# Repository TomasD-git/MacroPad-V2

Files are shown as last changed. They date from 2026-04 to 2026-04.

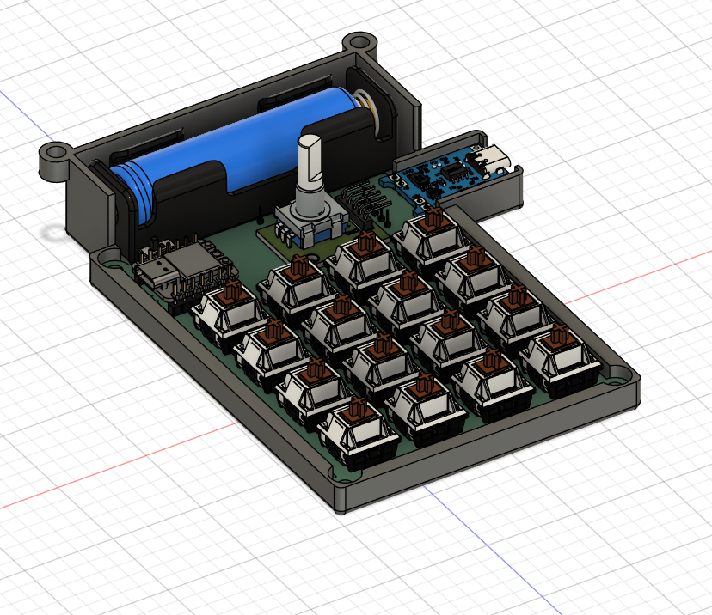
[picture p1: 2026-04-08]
Pictures/Screenshot 2026-04-08 103458.png

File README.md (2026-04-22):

# MacroPad-V2

A compact 16-key macro pad with rotary encoder and built-in battery — powered by ESP32, fully wireless.  



## Features

- 16 Programmable Keys  
- Rotary Encoder  
- Battery Powered  
- ESP32 with bluetooth  

## How It Works

The MacroPad-V2 uses a seeed xiao ESP32 S3 to manage key matrix and rotary encoder.  

Power is managed by a charging module.  

Firmware handles Bluetooth. The case is 3D printed, with space for the PCB, battery, keys and encoder.  

<details>
  <summary>Pictures</summary>
  







</details>

<details>
<summary>BOM</summary>

| Name | Purpose | Quantity | Total Cost (USD) | Link | Distributor |
|---|---|---|---|---|---|
| PCB | How would i even make it without PCB | 1 | 11.34 | https://jlcpcb.com | jlcpcb |
| Pin header 2.54mm | soldered onto the pcb then on top of that is the esp32(so it can be visible), the rotary encoder needs this as well | 1 | 3.08 | https://www.aliexpress.com/item/4000873858801.html | Aliepress |
| 1N4148W T4 SOD-123(Diode) | needed in switch matrix(prevents ghosting) | 1 | 2.16 | https://www.aliexpress.com/item/1005010653199938.html | Aliexpress |
| Seeed xiao ESP32 S3 | brain of everything, needed to power use and control all switches and rotary encoder | 1 | 9.06 | https://www.aliexpress.com/item/1005007341749305.html | Aliepress |
| M4 screws 20pcs, 8mm | screwed into heatset inserts to hold case and pcb together | 1 | 2.16 | https://www.aliexpress.com/item/32810872544.html | Aliexpress |
| Heatset inserts, M4 (OD5mm) 30pcs, Length 3mm | Will be melted into the 3D printed case and screws will be inserted into it to hold the case together | 1 | 2.43 | https://www.aliexpress.com/item/1005008666672949.html | Aliexpress |
| Battery holder | Holds battery in place | 1 | 1.84 | https://www.aliexpress.com/item/1005006783038553.html | Aliexpress |
| Battery | to store electricity and later power the esp32 | 1 | 8.85 | https://www.aliexpress.com/item/32810182330.html | Aliexpress |
| Slide switch | shut power to esp32 so it wont consume electricity when not used | 1 | 1.8 | https://www.aliexpress.com/item/1005005633418066.html | Aliexpress |
| Charging module | safely power esp32 and charge battery | 1 | 2.0 | https://www.aliexpress.com/item/1005007176376691.html | Aliexpress |
| Key switches | To use the macropad, (Self sourced) | 1 | 0.0 | https://www.aliexpress.com/item/1005007666734237.html | Aliexpress |
| Rotary encoder | is a part on the pcb | 1 | 1.47 | https://www.aliexpress.com/item/1005009040530746.html | Aliexpress |

</details>

<details>
  <summary>License</summary>

### MIT License

**Copyright (c) [2026] [TomasD-git]**

Permission is hereby granted, free of charge, to any person obtaining a copy
of this software and associated documentation files (the "Software"), to deal
in the Software without restriction, including without limitation the rights
to use, copy, modify, merge, publish, distribute, sublicense, and/or sell
copies of the Software, and to permit persons to whom the Software is
furnished to do so, subject to the following conditions:

The above copyright notice and this permission notice shall be included in all
copies or substantial portions of the Software.

THE SOFTWARE IS PROVIDED "AS IS", WITHOUT WARRANTY OF ANY KIND, EXPRESS OR
IMPLIED, INCLUDING BUT NOT LIMITED TO THE WARRANTIES OF MERCHANTABILITY,
FITNESS FOR A PARTICULAR PURPOSE AND NONINFRINGEMENT. IN NO EVENT SHALL THE
AUTHORS OR COPYRIGHT HOLDERS BE LIABLE FOR ANY CLAIM, DAMAGES OR OTHER
LIABILITY, WHETHER IN AN ACTION OF CONTRACT, TORT OR OTHERWISE, ARISING FROM,
OUT OF OR IN CONNECTION WITH THE SOFTWARE OR THE USE OR OTHER DEALINGS IN THE
SOFTWARE.

</details>

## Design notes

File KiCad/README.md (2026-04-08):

# Here you can find all KiCad related files

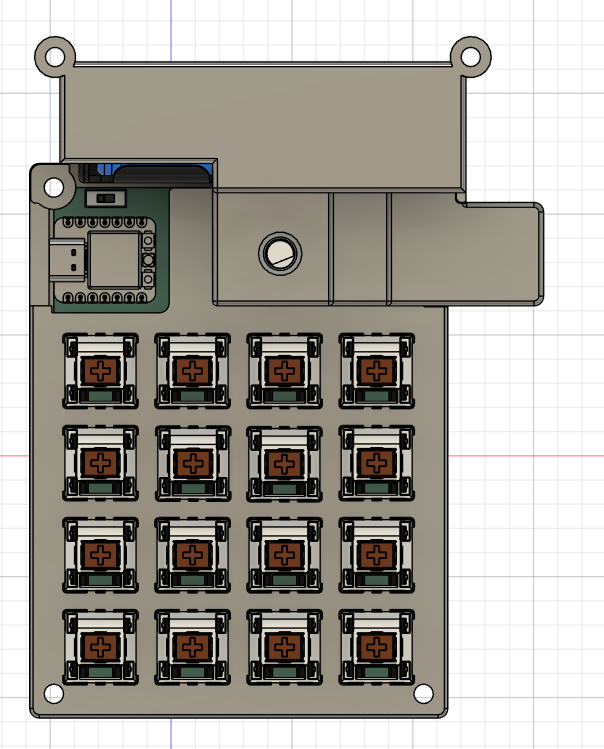
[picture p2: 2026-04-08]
Pictures/Screenshot 2026-04-08 103435.png

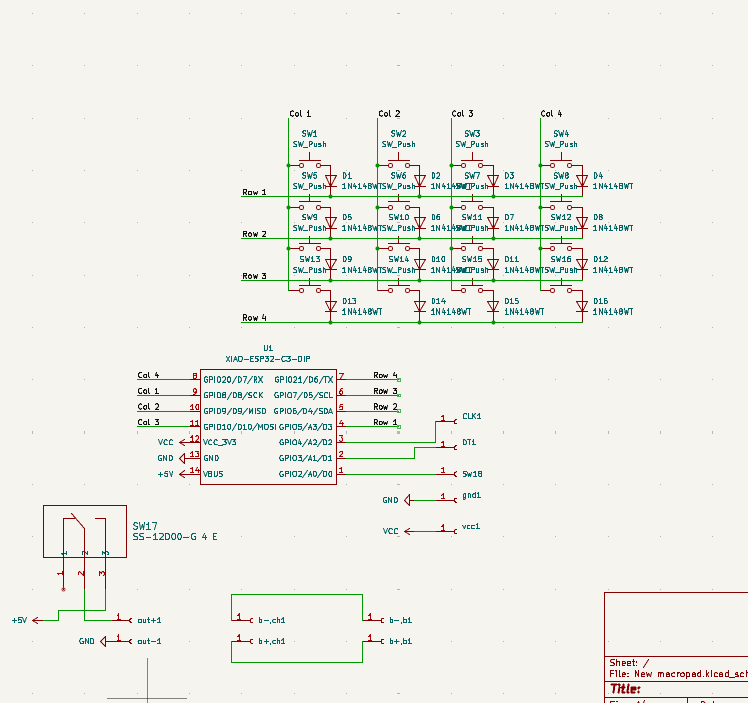
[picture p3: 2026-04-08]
Pictures/Screenshot 2026-04-08 092705.png

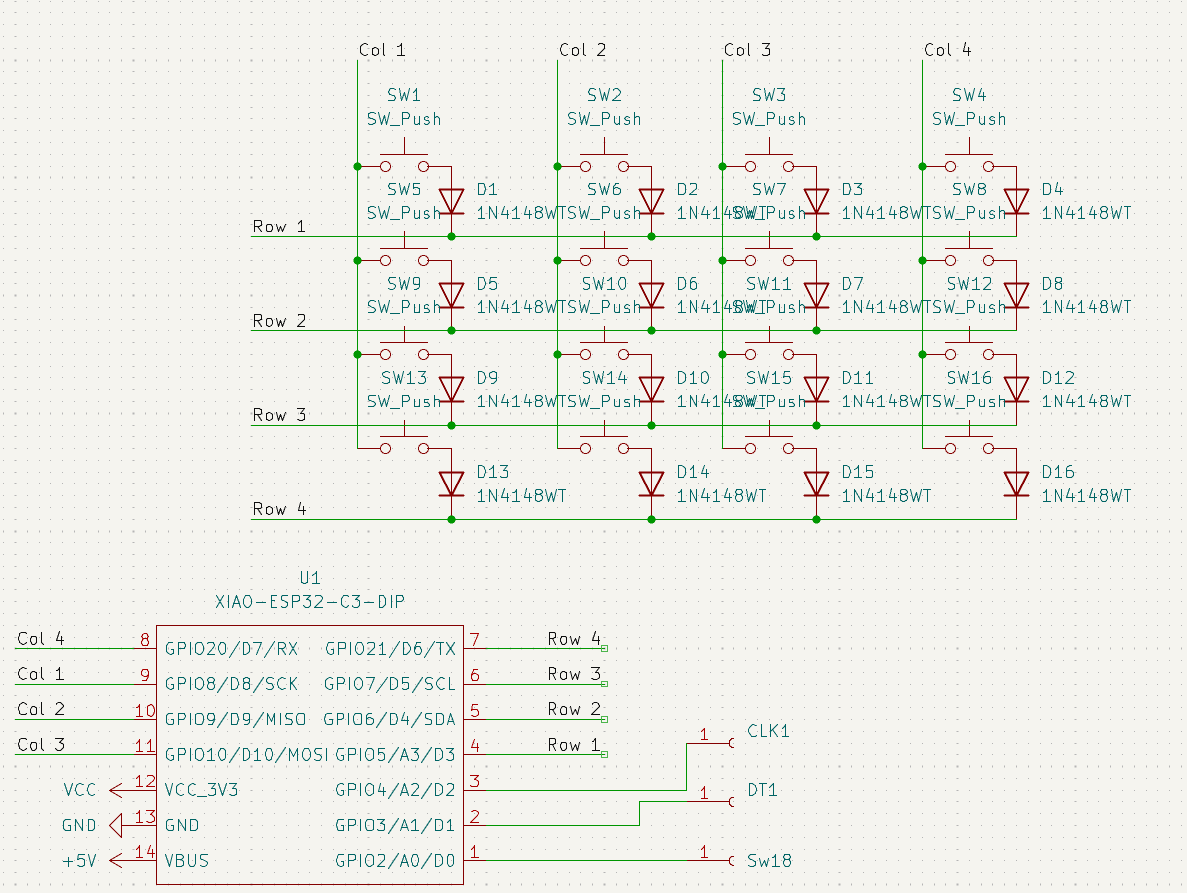
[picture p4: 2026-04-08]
Pictures/Screenshot 2026-04-08 092722.png

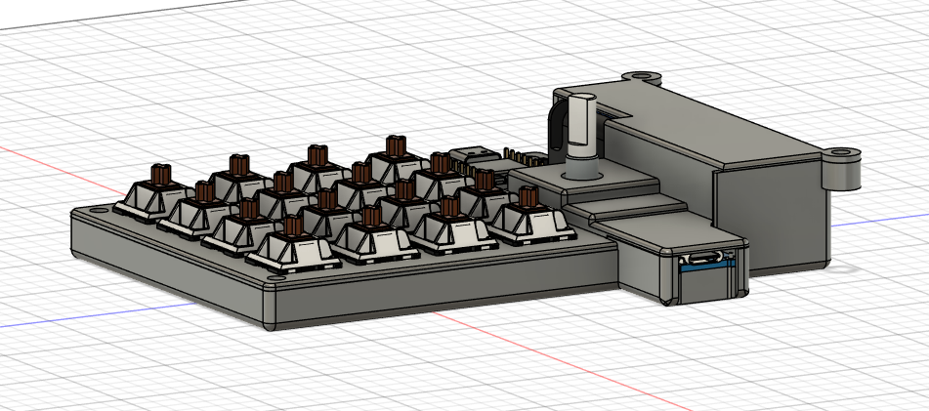
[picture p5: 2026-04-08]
Pictures/Screenshot 2026-04-08 103441.png

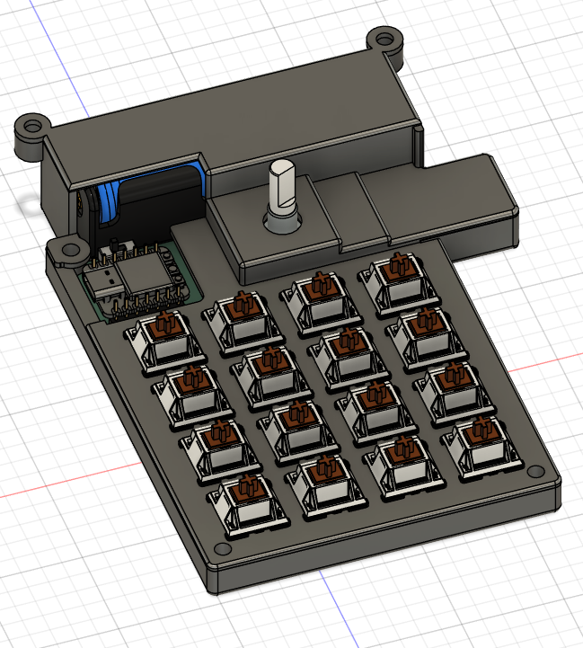
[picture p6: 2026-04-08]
Pictures/Screenshot 2026-04-08 103423.png

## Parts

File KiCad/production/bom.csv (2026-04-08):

Designator | Footprint | Quantity | Value | LCSC Part #
B+,B, B+,CH, B-,B, B-,CH, CLK, DT, GND, OUT+, OUT-, SW, VCC | PinHeader_1x01_P1.00mm_Vertical | 11 | Conn_01x01_Socket
D1, D10, D11, D12, D13, D14, D15, D16, D2, D3, D4, D5, D6, D7, D8, D9 | D_SOD-123 | 16 | 1N4148WT
SW1, SW10, SW11, SW12, SW13, SW14, SW15, SW16, SW2, SW3, SW4, SW5, SW6, SW7, SW8, SW9 | SW_Cherry_MX_PCB_1.00u | 16 | SW_Push
SW17 | 1P2T_SS-12D00_CNK | 1 | SS-12D00-G 4 E
U1 | Xiao_rp2040_AH_Pogo | 1 | XIAO-ESP32-C3-DIP

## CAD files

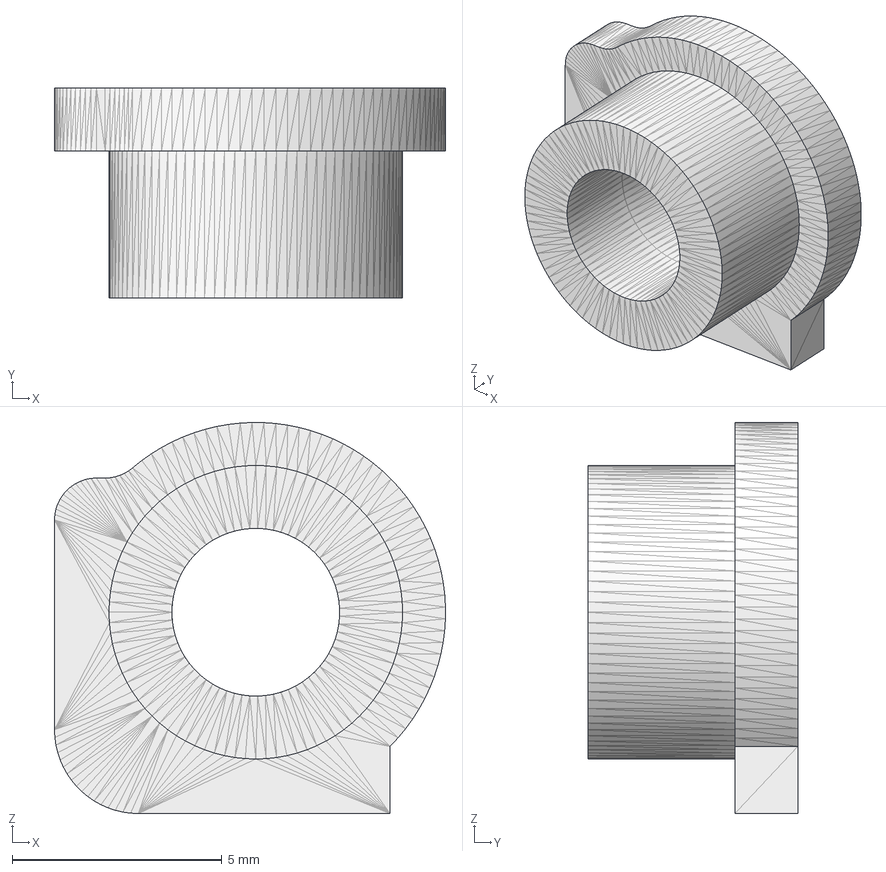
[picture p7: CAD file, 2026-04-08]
CAD/Top2.step
9.32 x 5.00 x 9.32 mm

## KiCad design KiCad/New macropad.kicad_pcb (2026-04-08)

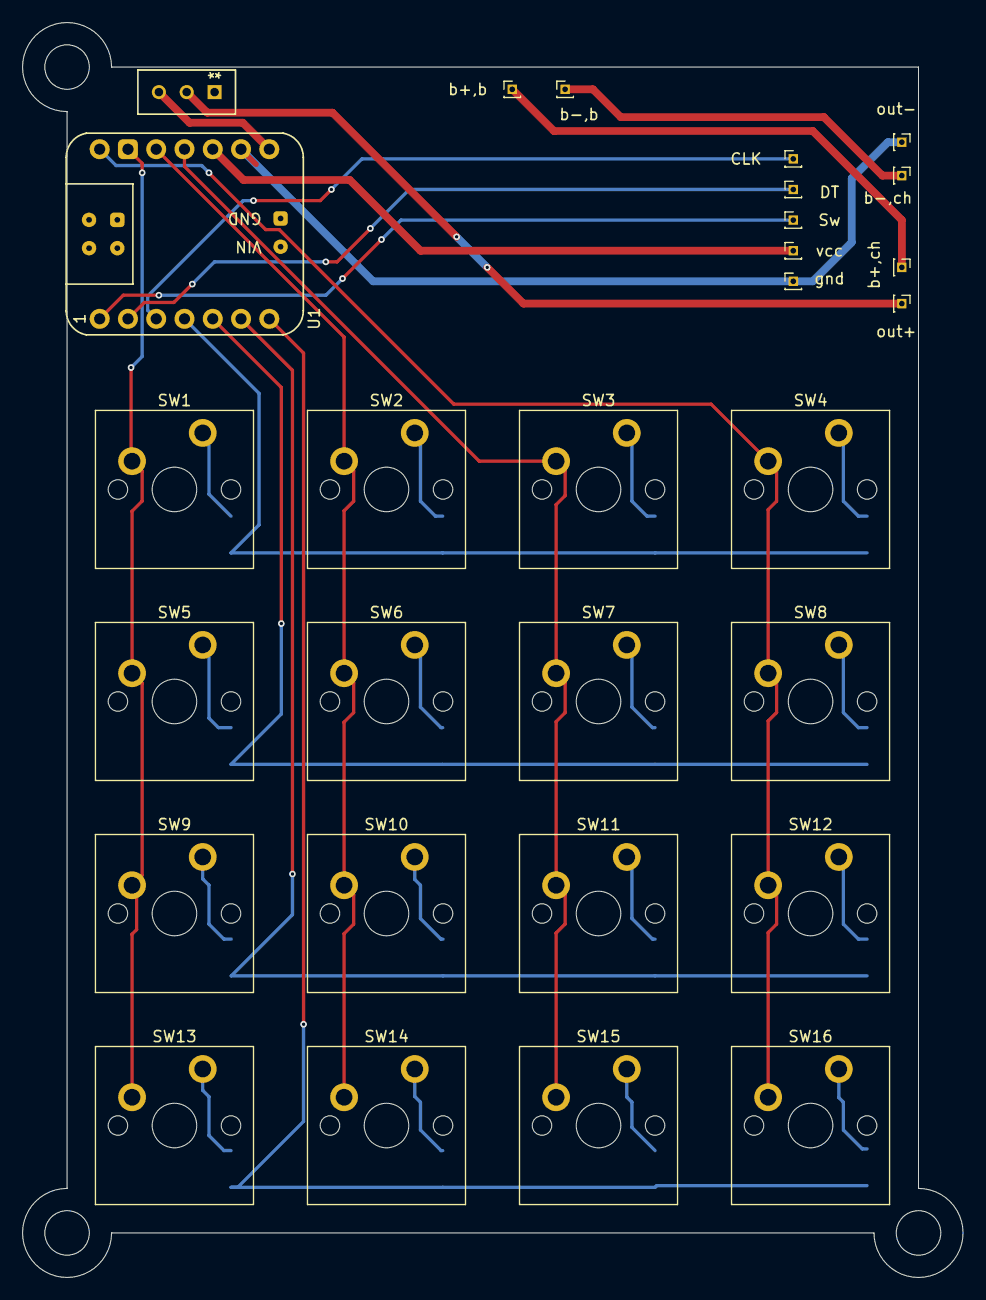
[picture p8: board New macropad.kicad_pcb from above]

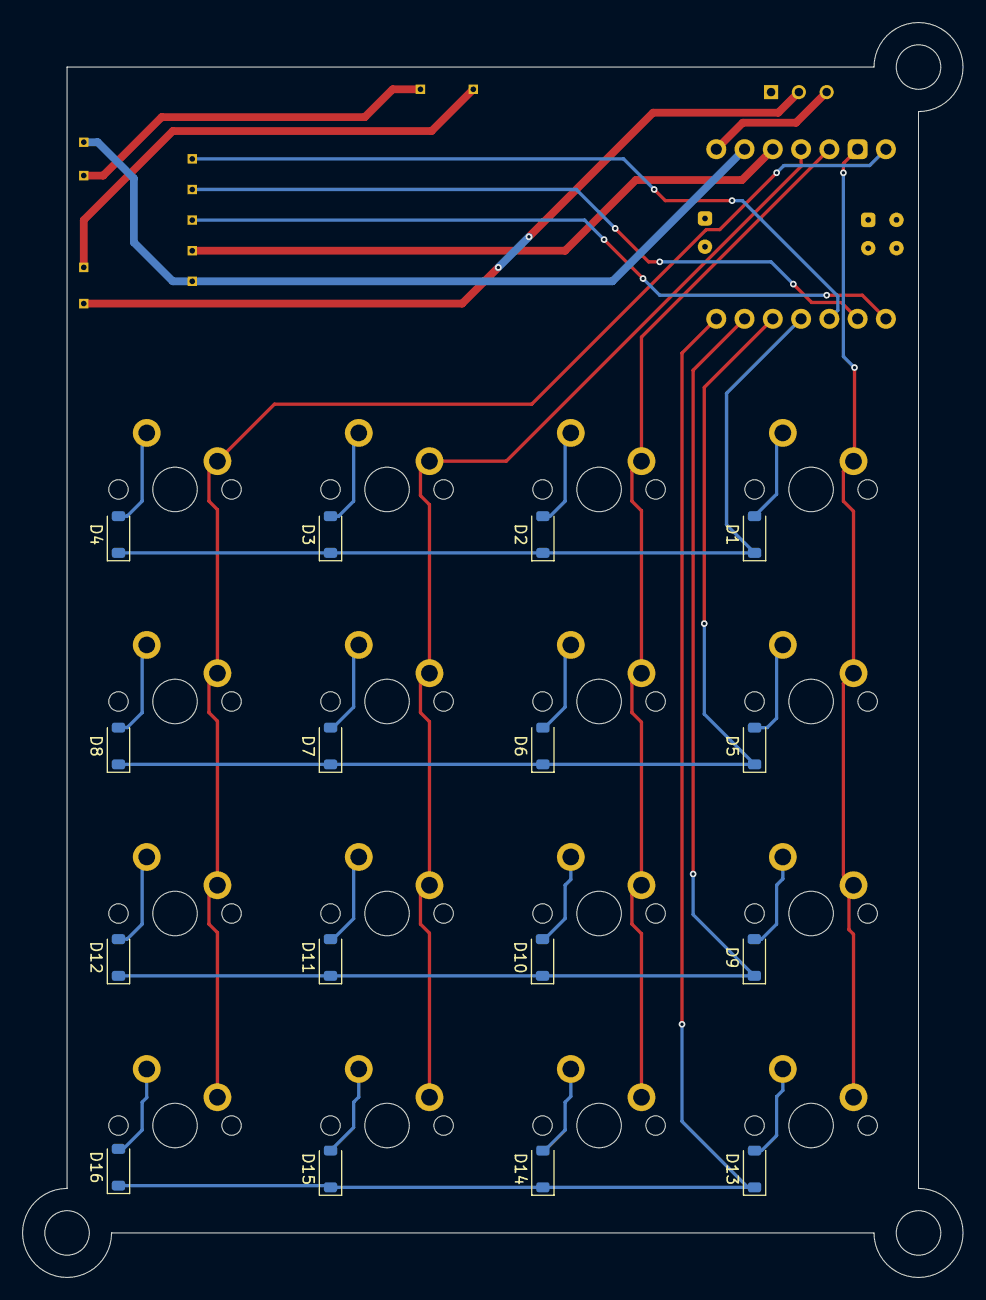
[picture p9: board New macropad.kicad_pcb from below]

Board: 2 copper layers, 84.5 x 112.7 mm, 45 parts (16 on the bottom side), 33 nets.

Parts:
CLK: Conn_01x01_Socket; PinHeader_1x01_P1.00mm_Vertical
D1, D2, D3, D4, D5, D6, D7, D8, D9, D10, D11, D12, D13, D14, D15, D16: 1N4148WT; D_SOD-123
DT: Conn_01x01_Socket; PinHeader_1x01_P1.00mm_Vertical
SW1, SW2, SW3, SW4, SW5, SW6, SW7, SW8, SW9, SW10, SW11, SW12, SW13, SW14, SW15, SW16: SW_Push; SW_Cherry_MX_PCB_1.00u
SW17: SS-12D00-G 4 E; 1P2T_SS-12D00_CNK
Sw: Conn_01x01_Socket; PinHeader_1x01_P1.00mm_Vertical
U1: XIAO-ESP32-C3-DIP; Xiao_rp2040_AH_Pogo
b+,b: Conn_01x01_Socket; PinHeader_1x01_P1.00mm_Vertical
b+,ch: Conn_01x01_Socket; PinHeader_1x01_P1.00mm_Vertical
b-,b: Conn_01x01_Socket; PinHeader_1x01_P1.00mm_Vertical
b-,ch: Conn_01x01_Socket; PinHeader_1x01_P1.00mm_Vertical
gnd: Conn_01x01_Socket; PinHeader_1x01_P1.00mm_Vertical
out+: Conn_01x01_Socket; PinHeader_1x01_P1.00mm_Vertical
out-: Conn_01x01_Socket; PinHeader_1x01_P1.00mm_Vertical
vcc: Conn_01x01_Socket; PinHeader_1x01_P1.00mm_Vertical

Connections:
+5V: SW17.3, U1.14 (VBUS)
/Col 1: SW1.1, SW5.1, SW9.1, SW13.1, U1.9 (GPIO8/D8/SCK)
/Col 2: SW2.1, SW6.1, SW10.1, SW14.1, U1.10 (GPIO9/D9/MISO)
/Col 3: SW3.1, SW7.1, SW11.1, SW15.1, U1.11 (GPIO10/D10/MOSI)
/Col 4: SW4.1, SW8.1, SW12.1, SW16.1, U1.8 (GPIO20/D7/RX)
/Row 1: D1.1 (K), D2.1 (K), D3.1 (K), D4.1 (K), U1.4 (GPIO5/A3/D3)
/Row 2: D5.1 (K), D6.1 (K), D7.1 (K), D8.1 (K), U1.5 (GPIO6/D4/SDA)
/Row 3: D9.1 (K), D10.1 (K), D11.1 (K), D12.1 (K), U1.6 (GPIO7/D5/SCL)
/Row 4: D13.1 (K), D14.1 (K), D15.1 (K), D16.1 (K), U1.7 (GPIO21/D6/TX)
GND: U1.13 (GND), gnd.1, out-.1
unnamed: CLK.1, U1.3 (GPIO4/A2/D2)
unnamed: D1.2 (A), SW1.2
unnamed: D2.2 (A), SW2.2
unnamed: D3.2 (A), SW3.2
unnamed: D4.2 (A), SW4.2
unnamed: D5.2 (A), SW5.2
unnamed: D6.2 (A), SW6.2
unnamed: D7.2 (A), SW7.2
unnamed: D8.2 (A), SW8.2
unnamed: D9.2 (A), SW9.2
unnamed: D10.2 (A), SW10.2
unnamed: D11.2 (A), SW11.2
unnamed: D12.2 (A), SW12.2
unnamed: D13.2 (A), SW13.2
unnamed: D14.2 (A), SW14.2
unnamed: D15.2 (A), SW15.2
unnamed: D16.2 (A), SW16.2
unnamed: DT.1, U1.2 (GPIO3/A1/D1)
unnamed: Sw.1, U1.1 (GPIO2/A0/D0)
unnamed: b+,b.1, b+,ch.1
unnamed: b-,b.1, b-,ch.1
unnamed: SW17.2, out+.1
VCC: U1.12 (VCC_3V3), vcc.1

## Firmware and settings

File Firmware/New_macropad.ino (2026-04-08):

#include <HijelHID_BLEKeyboard.h>
#include <Keypad.h>
HijelHID_BLEKeyboard keyboard("Tomik_Macropad");  // change to your prefered bluetooth name
#define ENC_CLK 4
#define ENC_DT  3
#define ENC_SW  2

const byte ROWS = 4;
const byte COLS = 4;
byte rowPins[ROWS] = {5, 6, 7, 21};
byte colPins[COLS] = {8, 9, 10, 20};
char keymap[ROWS][COLS] = {
  {'1','2','3','4'},
  {'5','6','7','8'},
  {'9','A','B','C'},
  {'D','E','F','G'}
}
;Keypad keypad = Keypad(makeKeymap(keymap), rowPins, colPins, ROWS, COLS);
int currentLayer = 1;
bool lastCLK = HIGH;
bool lastSW  = HIGH;
int8_t encState = 0;
unsigned long swDebounceTime = 0;
const unsigned long SW_DEBOUNCE = 50;
void setup() {
  pinMode(ENC_CLK, INPUT_PULLUP);
  pinMode(ENC_DT,  INPUT_PULLUP);
  pinMode(ENC_SW,  INPUT_PULLUP);

  keyboard.begin();
}
void loop() {
  if (!keyboard.isConnected()) return;
  handleKeypad();
  handleEncoder();
  delay(5);
}
// matrix
void handleKeypad() {
  char key = keypad.getKey();
  if (!key) return;
  // layer 1
  if (currentLayer == 1) {
    switch(key) {
      case '1': keyboard.print("1"); break;
      case '2': keyboard.print("2"); break;
      case '3': keyboard.print("3"); break;
      case '4': keyboard.print("+"); break;

      case '5': keyboard.print("4"); break;
      case '6': keyboard.print("5"); break;
      case '7': keyboard.print("6"); break;
      case '8': keyboard.print("-"); break;

      case '9': keyboard.print("7"); break;
      case 'A': keyboard.print("8"); break;
      case 'B': keyboard.print("9"); break;
      case 'C': keyboard.print("*"); break;

      case 'D': keyboard.print("0"); break;
      case 'E': keyboard.print("#"); break;
      case 'F': keyboard.print("/"); break;
      case 'G': keyboard.print("C"); break;
    }
  }
  // layer 2
  else {
    switch(key) {
      case '1': keyboard.write(KEY_F1); break;
      case '2': keyboard.write(KEY_F2); break;
      case '3': keyboard.write(KEY_F3); break;
      case '4': keyboard.write(KEY_F4); break;

      case '5': keyboard.write(KEY_F5); break;
      case '6': keyboard.write(KEY_F6); break;
      case '7': keyboard.write(KEY_F7); break;
      case '8': keyboard.write(KEY_F8); break;

      case '9': keyboard.write(KEY_F9); break;
      case 'A': keyboard.write(KEY_F10); break;
      case 'B': keyboard.write(KEY_F11); break;
      case 'C': keyboard.write(KEY_F12); break;

    }
  }
}
// rotary encoder
void handleEncoder() {
  bool currentCLK = digitalRead(ENC_CLK);
  bool currentDT  = digitalRead(ENC_DT);
  bool currentSW  = digitalRead(ENC_SW);
  if (currentCLK != lastCLK) {
    if (currentDT != currentCLK) encState++;
    else encState--;
    lastCLK = currentCLK;
  }
  if (encState >= 4) {
    keyboard.write(MEDIA_VOLUME_UP);
    encState = 0;
  } 
  else if (encState <= -4) {
    keyboard.write(MEDIA_VOLUME_DOWN);
    encState = 0;
  }
  if (currentSW != lastSW) {
    swDebounceTime = millis();
  }
  if ((millis() - swDebounceTime) > SW_DEBOUNCE) {
    if (currentSW == LOW && lastSW == HIGH) {
      toggleLayer();
    }
    lastSW = currentSW;
  }
}
// switch layer
void toggleLayer() {
  if (currentLayer == 1) {
    currentLayer = 2;
  } else {
    currentLayer = 1;
  }
}

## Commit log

2026-04-01 Update README with rotary encoder information
    Added links for rotary encoder and CAD file.
2026-04-02 Add charging module link to README
2026-04-02 Add slide switch link to README
2026-04-02 Add battery and battery holder links to README
2026-04-06 Add heatset inserts to the materials list
2026-04-08 Add initial README for CAD files
2026-04-08 added source and full CAD files
2026-04-08 added CAD files
    [Top2.step]
2026-04-08 Add initial README for KiCad files
2026-04-08 added kicad files
    [New macropad.kicad_pcb, New macropad.kicad_sch, bom.csv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]
2026-04-22 added BOM
    [BOM.csv]
2026-04-22 added gerber file
